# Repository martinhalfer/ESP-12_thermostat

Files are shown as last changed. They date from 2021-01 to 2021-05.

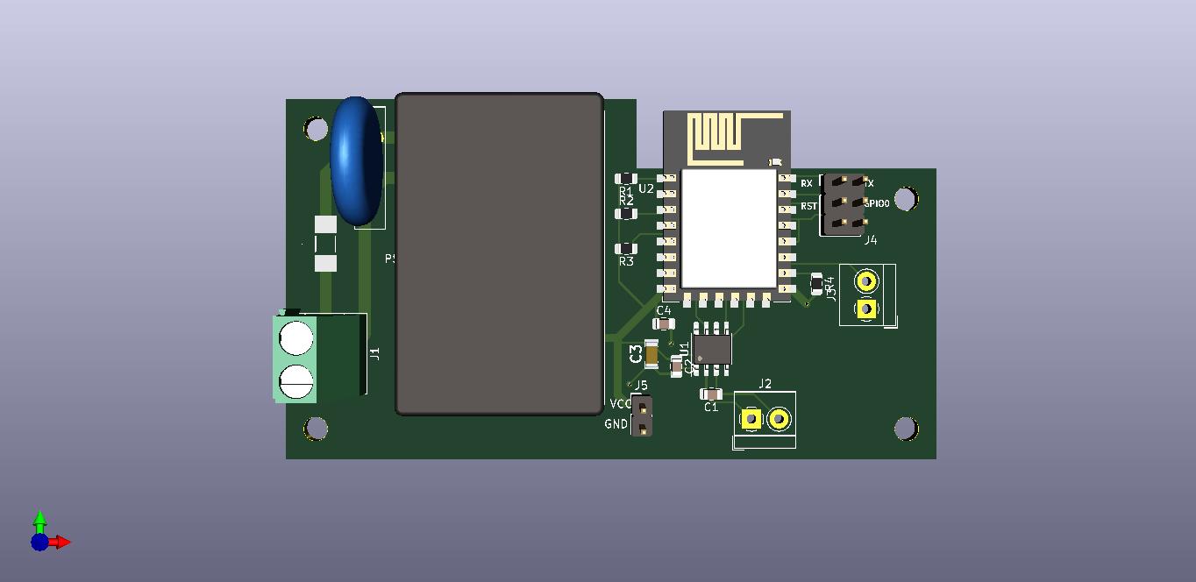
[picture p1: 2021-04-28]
gaggia.jpg

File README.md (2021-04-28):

# ESP-12_thermostat

This project can be used as a Wi-Fi enabled PID temperature controller. It is designed for use in appliances through some sort of relay. - Originally an espresso machine. The software is designed to interface through an MQTT broker - I use mosquitto running on a Hass.io server.

The features are:

Hardware:<br>
3.3V onboard power supply<br>
ESP8266 (ESP12) module for wifi connectivity and processing.<br>
MAX31855 thermocouple amplifier.<br>
Screw terminals for AC power, thermocouple input and relay output.<br>
Breakout connectors for programming of the ESP8266 after assembly of the PCB.

Software:<br>
Temperature readout through SPI<br>
PID controlled duty cycle relay output<br>
MQTT temperature readout and setpoint setting.
Written in the Ardunio IDE

Mounting hardware:
Can be mounted to coffee machine with M3 standoffs. 3D printable mounting base model in repository

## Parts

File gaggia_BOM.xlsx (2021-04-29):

Reference | Quantity | Value | Part number | Datasheet
C1 | 1 | 0.01 uF | 08051C103KAT2A | https://www.mouser.com/datasheet/2/40/X7RDielectric-777024.pdf
C2 C4 | 2 | .1 uF | 08055C104KAT2A | https://www.mouser.com/datasheet/2/40/X7RDielectric-777024.pdf
C3 | 1 | 100 uF | CL31A107MQHNNWE | https://www.mouser.com/datasheet/2/585/MLCC-1837944.pdf
F1 | 1 | Fuse | 0680L0500-05 | https://www.mouser.com/datasheet/2/643/ds_CP_0680L_series-1960423.pdf
J1 | 1 | Screw_Terminal_01x02 | TerminalBlock_Phoenix:TerminalBlock_Phoenix_MKDS-1,5-2_1x02_P5.00mm_Horizontal | ~
J2 J3 | 2 | Screw_Terminal_01x02 | TerminalBlock_4Ucon:TerminalBlock_4Ucon_1x02_P3.50mm_Horizontal | ~
J4 | 1 | Conn_02x03_Top_Bottom | Connector_PinHeader_2.54mm:PinHeader_2x03_P2.54mm_Vertical | ~
J5 | 1 | Conn_01x02_Male | Connector_PinHeader_2.54mm:PinHeader_1x02_P2.54mm_Vertical | ~
PS1 | 1 | RAC04-3.3SGA | RAC04-3.3SGB | https://www.mouser.com/datasheet/2/468/RAC04_GB-1711323.pdf
R1 R2 R3 R4 | 4 | 10kOhm | ERJ-6GEYJ103V | https://www.mouser.com/datasheet/2/315/AOA0000C301-1488782.pdf
RV1 | 1 | Varistor | TMOV14RP130E | https://www.mouser.com/datasheet/2/240/Littelfuse_Varistor_TMOV_ITMOV_Datasheet.pdf-693336.pdf
U1 | 1 | MAX31855KASA | Package_SO:SOIC-8_3.9x4.9mm_P1.27mm | http://datasheets.maximintegrated.com/en/ds/MAX31855.pdf
U2 | 1 | ESP-12E | RF_Module:ESP-12E | http://wiki.ai-thinker.com/_media/esp8266/esp8266_series_modules_user_manual_v1.1.pdf

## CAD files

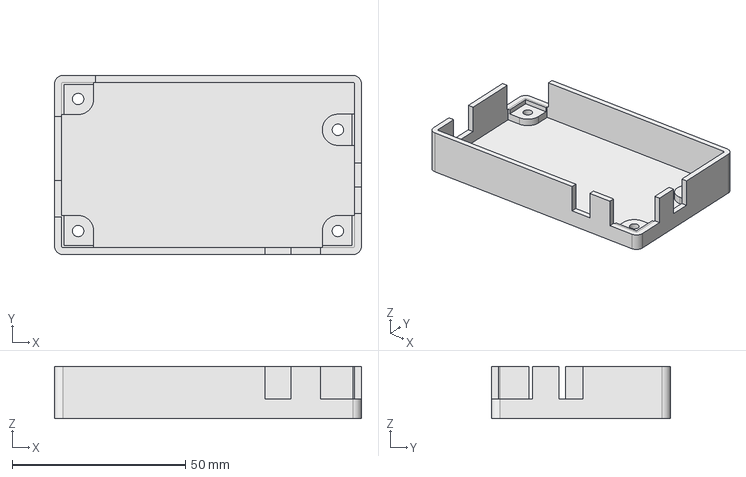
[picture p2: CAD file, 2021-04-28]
pidhousing.FCStd
88.5 x 51.7 x 15.0 mm

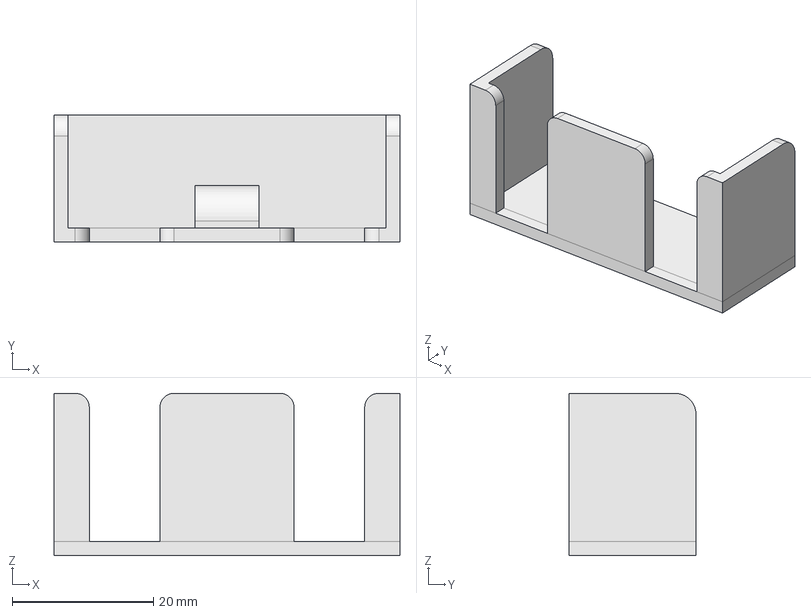
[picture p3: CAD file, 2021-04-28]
relaycover.FCStd
49.0 x 18.0 x 23.0 mm

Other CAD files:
pidhousing.stl
relaycover.stl

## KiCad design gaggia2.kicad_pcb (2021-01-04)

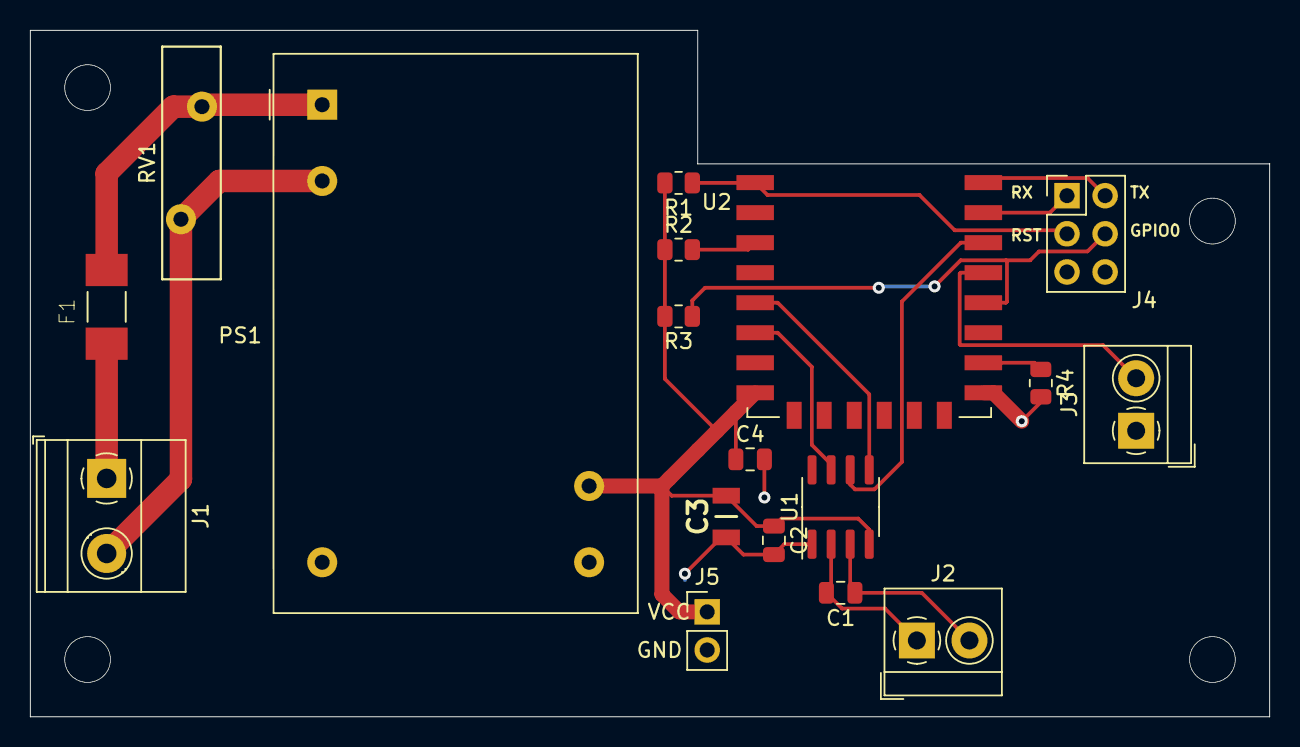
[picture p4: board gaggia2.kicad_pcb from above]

Board: 2 copper layers, 82.5 x 45.7 mm, 18 parts (0 on the bottom side), 17 nets.

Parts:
C1, C2, C4: C_Small; C_0805_2012Metric
C3: C_Small; CAPC3216X160N
F1: Fuse; FUSC6125X279N
J1: Screw_Terminal_01x02; TerminalBlock_Phoenix_MKDS-1,5-2_1x02_P5.00mm_Horizontal
J2, J3: Screw_Terminal_01x02; TerminalBlock_4Ucon_1x02_P3.50mm_Horizontal
J4: Conn_02x03_Top_Bottom; PinHeader_2x03_P2.54mm_Vertical
J5: Conn_01x02_Male; PinHeader_1x02_P2.54mm_Vertical
PS1: RAC04-3.3SGA; Converter_ACDC_RECOM_RAC04-xxSGx_THT
R1, R2, R3, R4: R; R_0805_2012Metric
RV1: Varistor; RV_Disc_D15.5mm_W3.9mm_P7.5mm
U1: MAX31855KASA; SOIC-8_3.9x4.9mm_P1.27mm
U2: ESP-12E

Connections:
GND: C2.2, C3.2, C4.2, J3.1, J5.2, PS1.4, R4.2, U1.1, U2.15
unnamed: C1.1, J2.2, U1.3
unnamed: C1.2, J2.1, U1.2
unnamed: F1.1, J1.1
unnamed: F1.2, PS1.1, RV1.1
unnamed: J1.2, PS1.2, RV1.2
unnamed: J3.2, U2.19
unnamed: J4.1, U2.21
unnamed: J4.2, U2.22
unnamed: J4.3, R1.1, U2.1
unnamed: J4.4, R3.1, U2.18
unnamed: R2.2, U2.3
unnamed: R4.1, U2.16
unnamed: U1.5, U2.5
unnamed: U1.6, U2.20
unnamed: U1.7, U2.6
VCC: C2.1, C3.1, C4.1, J5.1, PS1.5, R1.2, R2.1, R3.2, U1.4, U2.8

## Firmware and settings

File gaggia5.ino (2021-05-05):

#include <PID_v1.h>
#include <ESP8266WiFi.h>
#include <PubSubClient.h>
#include <MAX31855.h>
#define RelayPin D2 // D2 for external relay, D0 for testing with internal LED

// Update these with values suitable for your network.

const char* ssid = "xxxxxx"; // Input your SSID here
const char* password = "xxxxxxx"; // Input your WiFi password here
const char* mqtt_server = "0.0.0.0"; // The IP address of the MQTT server

//Define Variables we'll be connecting to
double Setpoint, Input, Output;
int average = 0;
int trigger = 1;

//Specify the links and initial tuning parameters
PID myPID(&Input, &Output, &Setpoint, 50, 25, 10, DIRECT);

WiFiClient espClient;
PubSubClient client(espClient);

char msg[50];
int value = 0;
int sensor = 0;
int32_t rawData = 0;


/*
  MAX31855(cs)

  cs - chip select
*/

MAX31855 myMAX31855(5); //chip select pin, for ESP8266 change to D4 (fails to BOOT/FLASH if pin LOW)


void setup_wifi() {


  delay(10);
 // We start by connecting to a WiFi network
  Serial.println();
  Serial.print("Connecting to ");
  Serial.println(ssid);

  WiFi.begin(ssid, password);

  while (WiFi.status() != WL_CONNECTED) {
    delay(500);
    Serial.print(".");
  }

  randomSeed(micros());

  Serial.println("");
  Serial.println("WiFi connected");
  Serial.println("IP address: ");
  Serial.println(WiFi.localIP());
}

//Establish callback and recieve new setpoint

void callback(char* topic, byte* payload, unsigned int length) {
  Serial.print("Message arrived [");
  Serial.print(topic);
  Serial.print("] ");
  for (int i = 0; i < length; i++) {
    Serial.print((char)payload[i]);
  }
  Serial.println();
  char buffer[128];

// Make sure here that `length` is smaller than the above buffer size. 
// Otherwise, you'd need a bigger buffer

// Form a C-string from the payload
memcpy(buffer, payload, length);
buffer[length] = '\0';

// Convert it to integer
char *end = nullptr;
double vaerdi = strtol(buffer, &end, 10);

Serial.println("New setpoint");
Serial.println(vaerdi);

// and assign to the PIDs Setpoint variable, but only if it is within the valid range

if (0 < vaerdi < 120) {

  Setpoint = vaerdi;
}

//Publish new setpoint (or old, if the  setpoint received is out of bounds)

client.publish("gaggia/temperature/state", String(Setpoint).c_str(), true);

}

void reconnect() {
  // Loop until we're reconnected
  while (!client.connected()) {
    Serial.print("Attempting MQTT connection...");
    // Create a random client ID
    String clientId = "ESP8266Client-";
    clientId += String(random(0xffff), HEX);
    // Attempt to connect, set your username and password for MQTT here
    if (client.connect(clientId.c_str(), "xxxxx", "xxxxx")) {
      Serial.println("connected");
      // Once connected, publish an announcement...
      client.publish("outTopic", "her er jeg igen");
      // ... and resubscribe
      client.subscribe("gaggia/temperature/set");
    } else {
      Serial.print("failed, rc=");
      Serial.print(client.state());
      Serial.println(" try again in 5 seconds");
      // Wait 5 seconds before retrying
      delay(5000);
    }
  }
}


int WindowSize = 3000; // Duration of the duty cycle window
unsigned long windowStartTime;

void setup() {
  pinMode(RelayPin, OUTPUT);     // Initialize the relay pin as an output
  Serial.begin(115200);
  setup_wifi();
  client.setServer(mqtt_server, 1883); // Change the MQTT servers port here if you have to
  client.setCallback(callback);
  windowStartTime = millis();

  //initialize the setpoint variable we're linked to
  Setpoint = 40;

    //tell the PID to range between 0 and the full window size of the duty cycle
  myPID.SetOutputLimits(0, WindowSize);

    //turn the PID on
  myPID.SetMode(AUTOMATIC);


  /* start MAX31855 */
  myMAX31855.begin();

  while (myMAX31855.getChipID() != MAX31855_ID)
  {
    Serial.println(F("MAX31855 error")); //(F()) saves string to flash & keeps dynamic memory free
    delay(5000);
  }
  Serial.println(F("MAX31855 OK"));
  
}


void loop() {

//first of all, check if we are still on wifi
  if (!client.connected()) {
    reconnect();
  }
//and let the wifi library do it's stuff   
  client.loop();


//Send error messages to serial 
  while (myMAX31855.detectThermocouple() != MAX31855_THERMOCOUPLE_OK)
  {
    switch (myMAX31855.detectThermocouple())
    {
      case MAX31855_THERMOCOUPLE_SHORT_TO_VCC:
        Serial.println(F("Thermocouple short to VCC"));
        break;

      case MAX31855_THERMOCOUPLE_SHORT_TO_GND:
        Serial.println(F("Thermocouple short to GND"));
        break;

      case MAX31855_THERMOCOUPLE_NOT_CONNECTED:
        Serial.println(F("Thermocouple not connected"));
        break;

      case MAX31855_THERMOCOUPLE_UNKNOWN:
        Serial.println(F("Thermocouple unknown error"));
        break;

      case MAX31855_THERMOCOUPLE_READ_FAIL:
        Serial.println(F("Thermocouple read error, check chip & spi cable"));
        break;
    }
    delay(5000);
  }



//Update PID Output each time a fifth of the timewindow has passed and trigger flag has been set to 1

unsigned long now = millis();

int sum = 0;
if ((now - windowStartTime > WindowSize / 5) && (trigger == 1)){

//read the sensor and compute PID output 

  for (int i = 0; i < 20; i++) { //loop for averaging and filtering dirty sensor data

    rawData = myMAX31855.readRawData(); //get raw data from max31855
    sensor = myMAX31855.getTemperature(rawData); //get temperature from raw data
  
      if ((average == 0) || (average - 8 < sensor < average + 8)) { //if average has not been calculated yet, or sensor reading is within +-8 of avg, add to sum
      sum = sum + sensor;
      }
      else { //else add the last average in place of a real sensor value
      sum = sum + average;
      }
    delay(2); //wait a litte and read sensor again.
  }

average = sum / 20; //divide by the number of sensor readings
trigger = 0; //set trigger flag to 0 to skip the sensor read and PID conpute next loops.
if (average < 175) {
  Input = (double)average; //If it is not a spike reading above 175C, convert average to double for the myPID.Compute() function
}
myPID.Compute();  
  
}

// Use output to adjust duty cycle of relay
  
  if (Output > now - windowStartTime) {
    digitalWrite(RelayPin, HIGH);
  }
  else digitalWrite(RelayPin, LOW);

//Update timewindow and transmit each time a timewindow has passed  
  if (now - windowStartTime > WindowSize){
    windowStartTime += WindowSize;
    ++value;
//send current values to serial for debugging  
    Serial.print(value);
    Serial.print("; ");
    Serial.print((millis() / 1000));
    Serial.print("; ");
    Serial.print(average);
    Serial.print("; ");
    Serial.print(Output);
    Serial.print("; ");
    Serial.println(Setpoint);
   
    
    
    
    
    if (average < 175) client.publish("gaggia/temperature/current", String(average).c_str(), true); // Publish average reading, if it is not a spike.


  trigger = 1; // reset the trigger to activate new sensor read and PID computation

    
  }

}

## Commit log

2021-04-28 Update gaggia5.ino
    Added averaging function to clean up sensor data
2021-04-28 Add files via upload
    3D printable cover for high voltage side of Fotek solid state relay
    [relaycover.FCStd, relaycover.stl]
2021-04-28 Add files via upload
    Housing base for PID controller. Isolates and protects high voltage leads.
    [pidhousing.FCStd, pidhousing.stl]
2021-04-29 Bill of materials for PCB
    [gaggia_BOM.xlsx]
2021-05-05 Update gaggia5.ino
    Improved sensor filtering and terminal output
